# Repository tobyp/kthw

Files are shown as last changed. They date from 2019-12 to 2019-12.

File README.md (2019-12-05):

This repository includes schematics, code, and instructions for building our hardware clone of the device from Steel Crate Games' game ["Keep Talking and Nobody Explodes"](http://www.keeptalkinggame.com/).

## Media

#### Demo
Demo

#### Timer Module
Timer Module

#### Morse Code
Morse Code

#### Simon Says
Simon Says

#### Wires/Capacitor
Wires/Capacitor

#### Memory
Memory

#### Password
Password

## Hardware

The code is written for an STM32F4 Discovery board, which you can probably get for around 25 €.
The rest of the materials probably cost another 25 €.
A complete list of required materials can be found in the [material list](MATERIALS.md).

There are also complete KiCad schematics in the [schematics](schematics) folder, along with some [assembly tips](ASSEMBLY.md).
 v
Our cube design requires 8 corner pieces, which you can 3D print from [this STL file](3dprints/corner.stl) (Designed for 6mm M2.5 screws with nuts. I lost the OpenSCAD file but I'm sure you can remake it pretty easily).

If you want to mess with the code, take a look at the [architecture description](ARCHITECTURE.md).

Lastly, there's a [quick reference how to play the game](MANUAL.md).

## Building The Software

The code does not use any libraries and requires only a GCC compiler and linker to build (prefix `arm-none-eabi`).
It can be uploaded to the board via USB using OpenOCD and the GDB debugger.
To read the console you will also need a 3.3V UART adapter.

From the repository root folder, run

	make
	openocd&
	arm-none-eabi-gdb -x .gdbinit

Use the `reload` command (defined in the `.gdbinit` file) to upload the software.

## License/Trademark

The code, schematics and 3d models are (c) 2017 Toby P. ([tobyp.net](http://www.tobyp.net)) and Thomas H., and licensed under the terms of the GNU GPL v3, see the file [LICENSE.txt](LICENSE.txt).

The files `startup.c`, `startup.h`, `stm32f407vg.h` and `stm32f407vg.ld` are no-brainers and released into the public domain.

The photographs are Copyright (c) 2017 Thomas H., all rights reserved. Do not distribute. Make your own.

The video is Copyright (c) 2017 Toby P. ([tobyp.net](http://www.tobyp.net)), all rights reserved. Do not distribute.

We are not affiliated with Steel Crate Games. This project is not endorsed by Steel Crate Games.
Steel Crate Games, Keep Talking and Nobody Explodes, and the Keep Talking and Nobody Explodes logo are all trademarks and/or registered trademarks of Steel Crate Games, Inc.

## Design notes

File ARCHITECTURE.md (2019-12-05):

# Architecture

## Shift Registers

The STM32F4 has limited GPIO pins, but we need a lot of I/O pins for all the displays and buttons.
The solution is shift registers - one pin on the board magically turns into 8 output pins!

In our code, we update the modules once per tick, allowing them to write new 8 bit values for the shift registers into a buffer, and at the end of the tick we apply those buffers to all shift registers in parallel, bit for bit.
To this end, the RCLK and SRCLK lines of all registers are connected, respectively.

## Buttons

For input pins, especially those for detecting button presses, it's a little more complicated.
All modules that have multiple buttons connect each of these between one shift register output pin, and connect them all to the same STM pin on the other side, with some diodes in between.
The code will then rapidly "poll" the buttons by cycling the shift register through (`0001` -> `0010` etc.).
The button polled in tick N will be read in tick N+1 (because the shift registers only get updated between logic ticks).
By caching the last-read button value and comparing it to the new value, we can detect if the button was pressed or released, and react accordingly.

## Bomb State Machine

The bomb object itself is actually a state machine.

 - `BS_READING_FLAGS` *(initial state)* The bomb stays in this state until it has read all flags.
 	The next state after that is determined by the "start" button (currently the capacitor button):
 	- if the button is down, it will enter `BS_WAITING`.
 	- otherwise, it will go straight to `BS_INITIALIZING_MODULES`.
 - `BS_WAITING` In this state, the bomb does fuck all.
 	When the start button is released, it goes to `BS_INITIALIZING_MODULES`.
 - `BS_INITIALIZING_MODULES` Here, all modules that are not yet marked as `MF_READY` are ticked until they are.
 	Typical initialization activities include filling an LCD screen, measuring initial ADC values, randomly generating the puzzles, etc.
 	When all modules are `MF_READY`, we go to `BS_COUNTDOWN`.
 - `BS_COUNTDOWN` You're in deep trouble now. The timer will keep counting down until all modules are `MF_COMPLETE` (the `MF_NEEDY` already count as complete).
 	If you make too many strikes or time runs out, the bomb will go to `BS_EXPLODED`, and god have mercy on your soul.
 	If you solve all modules, the bomb goes to `BS_DEFUSED`.
 - `BS_EXPLODED` Unless you did the smart thing and enabled mercy mode (`BF_MERCIFUL`), you now have an insufferable and incessant beeping to deal with.
 - `BS_DEFUSED` In this state, the bomb does nothing, but you've probably got a small high. Congratulations. Now try with fewer strikes or a lower timer, I dare you.

## LCD

The LCD module is very timing sensitive. Do not attempt to modify unless you have a priest present.

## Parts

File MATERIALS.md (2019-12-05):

# Materials

Total Value (ballpark): 50 €

## Consumable Materials

 - 7						100mm*100mm perfboards, one sided, (and a saw or dremel to cut the hub board)
 - ~10m					insulated wire (different colors are nice)
 - 2m					silver-plated copper wire
 - Enough				solder, flux, et
 - 6g					PLA filament
 - 24					Screws, M2.5, 6mm
 - 15cm					label tape (and a printer), for the serial number and module names
 - at least 30mm each	heat-shrink tubing, 2.5mm, white/yellow/red/blue/black
 - A dab of				hot glue (to stabilize some components, as necessary)

## Components

 - 1					STM32F4 Discovery
 - 2					15-pin female header
 - 4					25-pin female header
 - 1					9V block battery
 - 1					9V block clip
 - 1					9V to 5V regulator (e.g. via USB)
 - 2					bargraphs
 - 15				push-button switches
 - 2					buzzers (1 Buzz, 1 Beep)
 - 37				signal diodes
 - 2					8-bit DIP switches
 - 1					key switch
 - 1					LCD
 - 5					LED (green, small)
 - 3					LED (red, small)
 - 5					LED (white, small)
 - 5					LED (red/green/blue/yellow/yellow, large)
 - 1					Potentiometer (100kΩ)
 - 1					Trimmer potentiometer/variable resistor (100kΩ)
 - 139				Resistors, 1kΩ
 - at least one each	Resistors 100Ω, 510Ω, 1kΩ, 4.7kΩ, 10kΩ (Wires) (For other values, change the code)
 - 13				seven segment displays
 - 24				Shift Registers (74HC595)

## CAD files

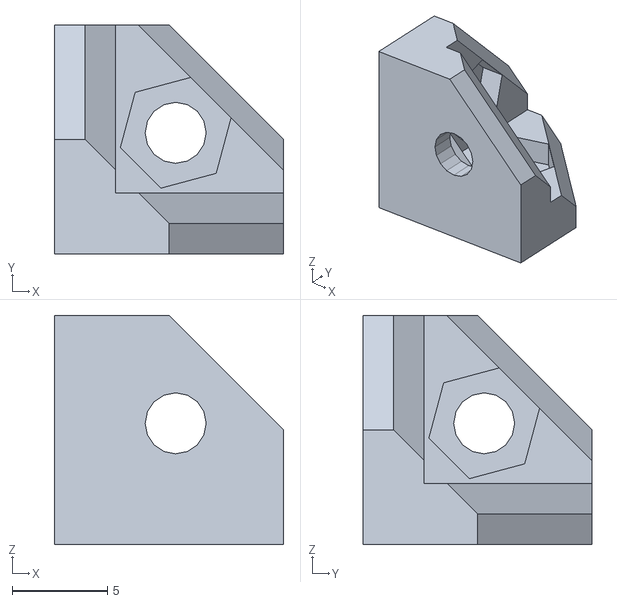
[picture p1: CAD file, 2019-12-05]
3dprints/corner.stl
12.0 x 12.0 x 12.0

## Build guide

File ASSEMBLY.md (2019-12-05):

# Assembly Notes

## Overall Notes

 - Drill the screw holes in the corners first. Ensure they actually line up.
 - Use a "Hub Board" with pin headers.
 	Solder the wires to the pins on one end, then stick the STM board on the other side.
 		Jumper cables will become unreliable if you connect/remove often.
 			Also, it's really hard to solder pin headers on the pad side of a perfboard.
 - Print or copy the shift register pin layout.
 	Meditate upon how you need to mirror this when you're looking at the bottom.
 		Resign yourself to the fact that you will mess it up at least once.
 		Rejoice in the fact that you will know it by heart when you're done.
 - Solder the components onto the board first.
 	Place them all nicely, hold/tape them there, then solder two pins (at two opposite corners for larger components) to keep then there.
 - Next, add flat uninsulated wire "rails" on the board for VCC and Ground.
 	Don't forget to connect OE and SCLR pins to GND/VCC respectively.
 - Add uninsulated wire "rails" for each clock signal, and connect all shift register clocks to that "rail".
 	Much easier to manage than "hopping" from register to register.
 - Solder one end of a long wire, about 30cm, for each input/output/"rail" that needs to attach to the hub board.
 	Prefer litz wire or other flexible wire for these inter-board connections.
 	You will need to bend/move them out of the way when assembling the modules, to make room for the innards.
 - Lastly, use insulated wires for the other connections.
 - Add the buzzers last to avoid your ears falling off during testing.
 - Put Wires/Capacitor opposite the timer module so you can rest the device on the button.
 - For multi-port inputs/outputs, e.g. multi-digit 7-segment displays, the port labelled 0 is the least significant.
 - Either place LEDs close to the board, or somewhere they won't be bent around a lot from handling.
 - Try to place the completion lights prominently and consistently in the top right corner.
 	They're important visual cues.
 - If the tick-tock beeper is too loud, putting a piece of tape over the hole might help.

## Hub Board

 - Use uninsulated wire "rails" for the clocks/VCC/GND. This is much nicer than soldering together 6 wire ends.

## Timer Module

 - Drill the hole for the key switch before you solder anything (but after you've decided on component placement).
 - The least significant bit of each flag shift register goes to the right switch on the DIP bank (from a player's perspective).

## Simon Says

 - Place the buttons near the center and the lights near the edge. Much harder to accidentally press a button while handling the device.
 - Use colored tape/marker/paint for the key caps if you don't have all the colors you need.

## Morse

 - If you want to mount your potentiometer through the board, drill the hole before you solder anything (but after you've decided on component placement).

## Password

 - Make sure you know whether the LCD board's pins are at the top or bottom of the screen (you may need to rotate it).
 - VCC for the LCD is on 5V, not 3.3V. Experiment wit VCC/V0/Backlight voltages. Be aware these conditions may change between battery and USB power situations.

## Memory

 - The left button is the least significant bit of the button-polling shift register.
 - The left button label display is `GP_MEM0_SER`.

## Wires/Capacitor

 - Use a button that will be pressed when the device is resting on this module's side.
 - Double check you have the bargraphs in the right order.
 - In the original, the wires are arranged vertically. The player must be able to recognize where "up" is for the wires in order to solve this module.
 - Make your "wires". These are actually resistors (see `wires.c` for values) that should be wrapped in heat-shrink tubes of the appropriate color.
 	You may need to add solder/fold the wire to ensure good contact in the pin headers.
 	Use the UART interface to see what colors the device can see.

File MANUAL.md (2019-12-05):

# How to play

 - Choose a serial number. Typically 8–10 digits long, half letters half digits, but ending in a digit.
 - [*optional/currently useless*] Randomly decide how many batteries you want to attach (if you have any)
 - [*optional/currently useless*] Decide what indicators you want (there's a list in the manual, and they can be lit or unlit)
 - [*optional/currently useless*] Decide whether to attach a parallel port.
 - Set the flags (see section below) according to the choices you made earlier, and also to select the desired strike limit (0 means first mistake → 💥) and time limit (if you choose 0, you're stupid and deserve what's coming to you.)
 - Choose and insert a random sequence of 3-6 "wires" (see Wires section of the [Assembly Notes](ASSEMBLY.md)) of red, blue, yellow, white or black for the wires module (the order matters!)
 - Insert the key.

To start playing immediately:
 - Turn the key! (and good luck to you.)

If you want to dump this monster you just configured on someone else:
 - Carefully put the device down so its weight keeps the capacitor button pressed.
 - Turn the key. (If the timer starts, the button wasn't correctly pressed. Go to step 1, do not collect $200.)
 - Carefully lure your victim to the device and get them to pick it up. 

We recommend "TickTock Mode" for use on unwitting victims, to let them immediately know they fucked up.
We also recommend making yourself scarce immediately or at least getting ear protectors.

## Flags

There are two blue banks of DIP switches on the timer module. You can use these to configure the characteristics, timer and strike limit of your device.
They're read once, immediately after turning the key, and will then be ignored. (So no, you can't cheat and increase your timer...)

Left DIP Bank: Strike/Timer configuration (left to right):

 - Timer: 8 min
 - Timer: 4 min
 - Timer: 2 min
 - Timer: 1 min
 - Timer: 30 s
 - Timer: 15 s
 - Strikes: 2
 - Strikes: 1

(To calculate the actual settings, add the strike/timer values of all switches that are ON, e.g. 010100 and 11 = 5 min, 3 strikes)

Right DIP Bank: Characteristics and other settings (left to right, Set these to match whatever ports/batteries/serial number you attach):

 - "TickTock Mode" (leave OFF if you're in a situation where ticking would make people a *liiiiitle bit too nervous...*)
 - "Merciful Mode" (if ON, there will only be a 2 second "beep" when you fail, instead of a horrifying, insufferable, neverending wail)
 - Lit `CAR` indicator (Currently unused, required by The Button)
 - Lit `FRK` indicator (Currently unused, required by The Button)
 - Parallel port attached (Currently unused, required by Complicated Wires)
 - Two or more batteries attached (Currently unused, required by Complicated Wires)
 - Serial number ends in an even digit (required by Wires and Complicated Wires)
 - Serial number contains a vowel (required by Simon Says)

## UART

To test the device, attach to the UART port on the timer panel.

Pins (top to bottom):
 - GND
 - N/C
 - TX input (currently unused by software)
 - RX output

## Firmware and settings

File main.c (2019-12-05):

/* KTHW - Hardware Clone of Keep Talking and Nobody Explodes
Copyright (C) 2017 Toby P., Thomas H.

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
You should have received a copy of the GNU General Public License
along with this program.  If not, see <http://www.gnu.org/licenses/>. */

#include <stdint.h>
#include <stddef.h>

#include "stm32f407vg.h"

#include "util.h"
#include "bomb.h"
#include "simonsays.h"
#include "morse.h"
#include "wires.h"
#include "capacitor.h"
#include "memory.h"
#include "password.h"

#include "pins.inc.h"

struct morse morse = {MORSE_MOD_INIT, &pins[GP_MORSE_LED], &pins[GP_MORSE_BTN], &adcs[ADC_MORSE], {&shregs[SR_MORSE_FREQ0], &shregs[SR_MORSE_FREQ1], &shregs[SR_MORSE_FREQ2], &shregs[SR_MORSE_FREQ3]}};
struct simonsays simonsays = {SIMONSAYS_MOD_INIT, &pins[GP_SIMONSAYS_BTN], &shregs[SR_SIMON_SAYS]};
struct wires wires = {WIRES_MOD_INIT, &shregs[SR_WIRES], &adcs[ADC_WIRES]};
struct capacitor capacitor = {CAPACITOR_MOD_INIT, &pins[GP_CAP_IN], {&shregs[SR_CAP0], &shregs[SR_CAP1]}};
struct memory memory = {MEMORY_MOD_INIT, &pins[GP_MEM_BTN_IN], &shregs[SR_MEM_BTN], &shregs[SR_MEM_STAGE], &shregs[SR_MEM_DISP], {&shregs[SR_MEM0], &shregs[SR_MEM1], &shregs[SR_MEM2], &shregs[SR_MEM3]}};
struct password password = {PASSWORD_MOD_INIT, &pins[GP_PWD_IN], &shregs[SR_PWD_SER], &lcds[LCD_PWD]};

struct bomb bomb = {{&pins[GP_FLAGS0_IN], &pins[GP_FLAGS1_IN]}, {&shregs[SR_FLAGS0], &shregs[SR_FLAGS1]}, &shregs[SR_STRIKE_COMPLETE], {&shregs[SR_TIMER0], &shregs[SR_TIMER1], &shregs[SR_TIMER2], &shregs[SR_TIMER3]}, &pins[GP_BUZZER], &pins[GP_BUZZER2], &pins[GP_CAP_IN]};

int main() {
	/* RCC/PLL */
	//f_{VCO} = f_{PLL IN} * \frac{N}{M}; 50 <= N <= 432; 2 <= M <= 63
	//N := 63
	//M := 12
	*RCC_PLLCFGR &= ~0x00007ffful;
	*RCC_PLLCFGR |=  0x00002fc0ul | 0x0000000cul;
	//f_{VCO} = 16 MHz * 21 / 4 = 84 MHz

	//f_{OTG_SDIO_RNG} = f_{VCO} / Q; 2 <= Q <= 15
	//Q := 2
	*RCC_PLLCFGR &= ~0x0f000000ul;
	*RCC_PLLCFGR |=  0x02000000ul;
	//f_{OTG_SDIO_RNG} = 84 MHz / 2 = 42 MHz

	*RCC_CR |= RCC_CR_PLLON;
	while ((*RCC_CR & RCC_CR_PLLRDY) == 0) { }

	/* GPIO */
	*RCC_AHB1ENR |= RCC_AHB1ENR_GPIOAEN | RCC_AHB1ENR_GPIOBEN | RCC_AHB1ENR_GPIOCEN | RCC_AHB1ENR_GPIODEN | RCC_AHB1ENR_GPIOEEN | RCC_AHB1ENR_GPIOHEN;

	for (uint32_t i=0; i<sizeof(pins)/(sizeof(struct gpio)); ++i) {
		struct gpio * p = &pins[i];
		uint32_t mode_mask = GM_MASK << (p->pin << 1);
		uint32_t mode = p->mode << (p->pin << 1);
		*GPIOx_MODER(p->base) &= ~mode_mask;
		*GPIOx_MODER(p->base) |= mode;
		if (p->mode == GM_IN) {
			*GPIOx_PUPDR(p->base) &= ~mode_mask;
			uint32_t pupd = GPP_DOWN << (p->pin << 1);
			*GPIOx_PUPDR(p->base) |= pupd;
		}
	}

	/* ADC */
	*RCC_AHB1ENR |= RCC_AHB1ENR_GPIOCEN;

	*GPIOx_MODER(GPIOC_BASE) &= ~0xful;
	*GPIOx_MODER(GPIOC_BASE) |=  0xful; //C0-1 analog

	*RCC_APB2ENR |= RCC_APB2ENR_ADC1EN;

	*ADCx_CR1(ADC1_BASE) |= ADC_CR1_EOCIE;
	*ADCx_CR2(ADC1_BASE) |= ADC_CR2_ADON;

	*ADCx_SMPR1(ADC1_BASE) |= 0x07ffffff;
	*ADCx_SMPR2(ADC1_BASE) |= 0x3fffffff; //sample all channels at 480 cycles
	*ADCx_SQR3(ADC1_BASE) |= adcs[0].channel;

	*NVIC_ISER(0) |= (1 << 18);

	*ADCx_CR2(ADC1_BASE) |= ADC_CR2_SWSTART;

	/* RNG */
	*RCC_AHB2ENR |= RCC_AHB2ENR_RNGEN;
	*RNG_CR |= RNG_CR_RNGEN;

	/* UART */
	*RCC_AHB1ENR |= RCC_AHB1ENR_GPIOAEN;
	*RCC_APB1ENR |= RCC_APB1ENR_USART4EN;

	*GPIOx_MODER(GPIOA_BASE) &= ~0xful;
	*GPIOx_MODER(GPIOA_BASE) |= 0xaul; //PA0 and PA1 Alternate Function

	*GPIOx_AFRL(GPIOA_BASE) &= ~0xfful;
	*GPIOx_AFRL(GPIOA_BASE) |= 0x88ul; //PA0 and PA1 to AF8 (UART4 TX/RX)

	*USARTx_BRR(UART4_BASE) |= 139; //139 is 115200 Bd, 1667 is 9600 Bd at 16 MHz SYSCLK with OVER8=0
	*USARTx_CR1(UART4_BASE) |= USART_CR1_UE | USART_CR1_TE | USART_CR1_RE;
	uart_enabled = 1;

	/* LCD power up */
	delay(150);

	/* Bomb */
	bomb_add_module(&bomb, &capacitor.module);
	bomb_add_module(&bomb, &password.module);
	bomb_add_module(&bomb, &memory.module);
	bomb_add_module(&bomb, &wires.module);
	bomb_add_module(&bomb, &morse.module);
	bomb_add_module(&bomb, &simonsays.module);

	/* System Tick Timer */
	*NVIC_PRIn(3) &= 0xff000000ul;
	*NVIC_PRIn(3) |= 0x0f000000ul;
	*STK_LOAD = 2000000ul / TICKS_PER_SEC;
	*STK_VAL = 0;
	*STK_CTRL |= (STK_TICKINT | STK_ENABLE);

	/* And now, we wait. */
	while(1) { }

	return 0;
}

uint8_t current_adc = 0;

void __isr_adc() {
	adcs[current_adc].value = *ADCx_DR(ADC1_BASE);
}

void __isr_systick() {
	//*GPIOx_ODR(GPIOD_BASE) ^= 0x1000;  //D12, green LED on the discovery board
	tick(&bomb);
	/* LCDs (part 1) */
	for (uint8_t i=0; i<(sizeof(lcds)/sizeof(struct lcd)); ++i) {
		lcds[i].lcd_data->value = lcds[i].cmd;
	}
	/* Shift Registers. We shift all registers in parallel, eight times per systick. */
	for (uint8_t i=0; i<(sizeof(shregs)/sizeof(struct shreg)); ++i) {
		shregs[i].value_cache = shregs[i].value;
	}
	for (uint8_t i=0; i<8; ++i) {
		for (uint8_t j=0; j<(sizeof(shregs)/sizeof(struct shreg)); ++j) {
			gpio_set(shregs[j].ser, shregs[j].value_cache & 0x1);
			shregs[j].value_cache >>= 1;
		}
		gpio_set(&pins[GP_SR_SRCLK], 1); gpio_set(&pins[GP_SR_SRCLK], 0);
	}
	gpio_set(&pins[GP_SR_RCLK], 1); gpio_set(&pins[GP_SR_RCLK], 0);
	/* LCDs (part 2) */
	for (uint8_t i=0; i<(sizeof(lcds)/sizeof(struct lcd)); ++i) {
		if (lcds[i].mode < LCD_NONE) {
			gpio_set(lcds[i].lcd_en, 1);
			if (lcds[i].mode) gpio_set(lcds[i].lcd_rs, 1);
			else gpio_set(lcds[i].lcd_rs, 0);

			delay(1);

			gpio_set(lcds[i].lcd_en, 0);
			lcds[i].mode = LCD_NONE;
		}
	}
	/* ADCs */
	current_adc = (current_adc + 1) % (sizeof(adcs)/sizeof(struct adc));
	*ADCx_SQR3(ADC1_BASE) &= ~0x1f;
	*ADCx_SQR3(ADC1_BASE) |= adcs[current_adc].channel;
	*ADCx_CR2(ADC1_BASE) |= ADC_CR2_SWSTART;
}

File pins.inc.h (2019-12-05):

#define PIN_0	0
#define PIN_1	1
#define PIN_2	2
#define PIN_3	3
#define PIN_4	4
#define PIN_5	5
#define PIN_6	6
#define PIN_7	7
#define PIN_8	8
#define PIN_9	9
#define PIN_10	10
#define PIN_11	11
#define PIN_12	12
#define PIN_13	13
#define PIN_14	14
#define PIN_15	15

#define GM_MASK		0x3
#define GM_OUT		0x1
#define GM_IN		0x0
#define GPP_DOWN	0x2

/* Preprocessor magic. */
#define GPIO_OUT(bank, idx) {GPIO##bank##_BASE, GM_OUT, PIN_##idx}
#define GPIO_IN(bank, idx) {GPIO##bank##_BASE, GM_IN, PIN_##idx}

/*
//Useful if you temporarily want to disable a pin - just uncomment and use the DUMMY port
static const uint32_t dummy_gpio_port[10] = {0};
#define GPIODUMMY_BASE ((uint32_t)&dummy_gpio_port)
*/

/* To use new ports, also adjust the GPIO section of main() */

enum {
	GP_SR_SRCLK,
	GP_SR_RCLK,

	GP_TIMER0_SER,
	GP_TIMER1_SER,
	GP_TIMER2_SER,
	GP_TIMER3_SER,
	GP_BUZZER,
	GP_BUZZER2,
	GP_FLAGS0_SER,
	GP_FLAGS1_SER,
	GP_FLAGS0_IN,
	GP_FLAGS1_IN,
	GP_STRIKES_SER,

	GP_SIMONSAYS_SER,
	GP_SIMONSAYS_BTN,

	GP_MORSE_FREQ0_SER,
	GP_MORSE_FREQ1_SER,
	GP_MORSE_FREQ2_SER,
	GP_MORSE_FREQ3_SER,
	GP_MORSE_LED,
	GP_MORSE_BTN,

	GP_WIRES_SER,

	GP_CAP0_SER,
	GP_CAP1_SER,
	GP_CAP_IN,

	GP_MEM0_SER,
	GP_MEM1_SER,
	GP_MEM2_SER,
	GP_MEM3_SER,
	GP_MEM_DISP_SER,
	GP_MEM_STAGE_SER,
	GP_MEM_BTN_SER,
	GP_MEM_BTN_IN,

	GP_PWD_SER,
	GP_PWD_IN,
	GP_PWD_LCD_SER,
	GP_PWD_LCD_RS,
	GP_PWD_LCD_EN,
};

struct gpio pins[] = {
	GPIO_OUT(C, 3), //GP_SR_SRCLK
	GPIO_OUT(C, 2), //GP_SR_RCLK

	GPIO_OUT(A, 3), //GP_TIMER0_SER
	GPIO_OUT(A, 5), //GP_TIMER1_SER
	GPIO_OUT(A, 7), //GP_TIMER2_SER
	GPIO_OUT(C, 5), //GP_TIMER3_SER
	GPIO_OUT(B, 1), //GP_BUZZER
	GPIO_OUT(B, 15), //GP_BUZZER2
	GPIO_OUT(B, 12), //GP_FLAGS0_SER
	GPIO_OUT(B, 14), //GP_FLAGS1_SER
	GPIO_IN(D, 8), //GP_FLAGS0_IN
	GPIO_IN(D, 10), //GP_FLAGS1_IN
	GPIO_OUT(B, 0), //GP_STRIKES_SER

	GPIO_OUT(D, 11), //GP_SIMONSAYS_SER
	GPIO_IN(E, 8), //GP_SIMONSAYS_BTN

	GPIO_OUT(E, 9), //GP_MORSE_FREQ0_SER
	GPIO_OUT(E, 11), //GP_MORSE_FREQ1_SER
	GPIO_OUT(E, 13), //GP_MORSE_FREQ2_SER
	GPIO_OUT(E, 15), //GP_MORSE_FREQ3_SER
	GPIO_OUT(E, 10), //GP_MORSE_LED
	GPIO_IN(E, 12), //GP_MORSE_BTN

	GPIO_OUT(E, 14), //GP_WIRES_SER

	GPIO_OUT(E, 2), //GP_CAP0_SER
	GPIO_OUT(C, 7), //GP_CAP1_SER
	GPIO_IN(E, 3), //GP_CAP_IN

	GPIO_OUT(E, 4), //GP_MEM0_SER
	GPIO_OUT(E, 6), //GP_MEM1_SER
	GPIO_OUT(C, 14), //GP_MEM2_SER
	GPIO_OUT(B, 8), //GP_MEM3_SER
	GPIO_OUT(B, 9), //GP_MEM_DISP_SER
	GPIO_OUT(C, 15), //GP_MEM_STAGE_SER
	GPIO_OUT(C, 13), //GP_MEM_BTN_SER
	GPIO_IN(E, 5), //GP_MEM_BTN_IN

	GPIO_OUT(D, 3), //GP_PWD_SER
	GPIO_IN(C, 12), //GP_PWD_IN
	GPIO_OUT(D, 4), //GP_PWD_LCD_SER
	GPIO_OUT(D, 2), //GP_PWD_LCD_RS
	GPIO_OUT(D, 0), //GP_PWD_LCD_EN
};

//pins that are hard-wired, or initialized to AF on reset:
//A13: JTMS
//A14: JLCK
//A15: JTDI
//B3: JLDO
//B4: NJTRST
//D5: STM32F4Discovery: red LED
//D12: STM32F4Discovery: green LED
//D13: STM32F4Discovery: orange LED
//D14: STM32F4Discovery: red LED
//D15: STM32F4Discovery: blue LED

enum {
	SR_TIMER0,	//seconds (ones), use util.h's sevenseg_digits
	SR_TIMER1,	//seconds (tens), use util.h's sevenseg_digits
	SR_TIMER2,	//minutes (ones), use util.h's sevenseg_digits
	SR_TIMER3,	//minutes (tens), use util.h's sevenseg_digits
	SR_STRIKE_COMPLETE,	//(MSB) complete 5..1, strike 3..1 (LSB)
	SR_FLAGS0,	//see BF_* constants in bomb.h
	SR_FLAGS1,	//(MSB) 6 bits = time / 15s; 2 bits = strike limit

	SR_SIMON_SAYS,

	SR_MORSE_FREQ0,
	SR_MORSE_FREQ1,
	SR_MORSE_FREQ2,
	SR_MORSE_FREQ3,

	SR_WIRES,

	SR_CAP0,
	SR_CAP1,

	SR_MEM0,
	SR_MEM1,
	SR_MEM2,
	SR_MEM3,
	SR_MEM_DISP,
	SR_MEM_STAGE,
	SR_MEM_BTN,

	SR_PWD_LCD,
	SR_PWD_SER,
};

struct shreg shregs[] = {
	{&pins[GP_TIMER0_SER], 0},
	{&pins[GP_TIMER1_SER], 0},
	{&pins[GP_TIMER2_SER], 0},
	{&pins[GP_TIMER3_SER], 0},
	{&pins[GP_STRIKES_SER], 0},
	{&pins[GP_FLAGS0_SER], 0},
	{&pins[GP_FLAGS1_SER], 0},

	{&pins[GP_SIMONSAYS_SER], 0},

	{&pins[GP_MORSE_FREQ0_SER], 0},
	{&pins[GP_MORSE_FREQ1_SER], 0},
	{&pins[GP_MORSE_FREQ2_SER], 0},
	{&pins[GP_MORSE_FREQ3_SER], 0},

	{&pins[GP_WIRES_SER], 0},

	{&pins[GP_CAP0_SER], 0},
	{&pins[GP_CAP1_SER], 0},

	{&pins[GP_MEM0_SER], 0},
	{&pins[GP_MEM1_SER], 0},
	{&pins[GP_MEM2_SER], 0},
	{&pins[GP_MEM3_SER], 0},
	{&pins[GP_MEM_DISP_SER], 0},
	{&pins[GP_MEM_STAGE_SER], 0},
	{&pins[GP_MEM_BTN_SER], 0},

	{&pins[GP_PWD_LCD_SER], 0},
	{&pins[GP_PWD_SER], 0},
};

/* ADCs */
/* To add more ADCs, also adjust the ADC section of main() */
enum {
	ADC_MORSE,
	ADC_WIRES,
};

struct adc adcs[] = {
	{10, 0},
	{11, 0},
};

/* LCDs */
enum {
	LCD_PWD,
};

struct lcd lcds[] = {
	{&pins[GP_PWD_LCD_RS], &pins[GP_PWD_LCD_EN], &shregs[SR_PWD_LCD], LCD_NONE, 0},
};

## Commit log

2019-12-04 Finish Simon Says; Refactor into multiple files; Add UART
2019-12-04 Implement morse blinking and button (ADC missing); Reorganize GPIO ports a bit; Generalize modules
    [bomb.c, main.c, morse.c]
2019-12-04 Refactor IO; Initialize ADC; Finish Morse module
2019-12-04 Reorganize thingamajigs; Implement simple wires.
2019-12-04 Implement capacitor.
2019-12-04 Implement buzzer and module completion LEDs (Untested)
    [bomb.c, main.c, wires.c]
2019-12-04 Fine tuning and small fixes
    [bomb.c, main.c, morse.c]
2019-12-04 Add schematics
    [kthw_memory.sch, kthw_morse.sch, kthw_password.sch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]
2019-12-04 Use ADC for wires (color =^= resistance) Remove UART flag (always on now), add LBL_CAR flag
2019-12-04 fixed wire resistor values
    [wires.c]
2019-12-05 Clean up
    [kthw_memory.sch, kthw_morse.sch, kthw_password.sch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]
2019-12-05 Add Documentation and 3D Print files
    [corner.stl]

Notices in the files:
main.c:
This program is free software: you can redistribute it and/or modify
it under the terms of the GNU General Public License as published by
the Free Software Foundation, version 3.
